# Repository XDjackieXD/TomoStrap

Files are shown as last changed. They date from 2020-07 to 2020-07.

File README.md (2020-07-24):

 # TomoStrap
 
 The code residing in the "microcontroller" and "pebble" directories was written by me, Jakob (Jack/XDjackieXD), as part of the diploma thesis you are required to do for your A Level at a higher technical school in Austria.
 The KiCAD files inside the "hardware" directory, designed by Jakob Z., represent the hardware the aforementioned code runs on.
 
 ## Introduction
 
 The main topic of the diploma thesis was to build a device similar to http://chrisharrison.net/projects/tomo/tomo.pdf while increasing mobility by using a Pebble smartwatch as the base.
 During development I snuck in a MAX30102 pulseoximeter which basically is the main feature as of now.
 
 ## Usage
 
 ### Microcontroller Firmware
 
 To compile the Firmware for the KL03 ARM processor, it'll be the easiest route to install the kinetis design studio. The hardware abstraction layer was generated using NXP's MCUXpresso tool.
 Most parts of the code are written in a way that should allow for fairly easy porting to other microcontroller platforms.
 Currently the handlers for data received are inside the library. Changing this to callbacks should be easy though.
 The firmware isn't complete by any means but contineous SpO2 and pulse measurements are working as intended. Things that need to be addressed before "production" use include proper power management and automatic gain control for the MAX30102's LEDs and configurable ADC ranges as those values are currently hard coded which lead to unreliable measurements in many situations.
 
 ### Pebble App
 
 The included pebble app is able to display any SpO2 and pulse data sent by the microcontroller. Impedance data is currently only printed into the debug log of the Pebble app.
 
 ## License
 
 All code written by me and the SpO2 calculation library is licensed under the MIT license (LICENSE-software.txt).
 The dstring library used for SpO2 debugging using FlexiPlot is licensed under the Creative Commons license (LICENSE-dstring.txt).
 All other source code files included in the microcontroller firmware directory (everything not inside of the "source" directory) is licensed under the respective licenses stated in the source file headers.

 The hardware is Licensed under the terms of the Creative Commons Attribution Sharealike 4.0 license (LICENSE-hardware.txt) with the exception of the kicad library by Michael Cousins which is licensed under the terms of the Creative Commons Attribution Sharealike 3.0 Unported license (LICENSE-kicad-libs.txt).

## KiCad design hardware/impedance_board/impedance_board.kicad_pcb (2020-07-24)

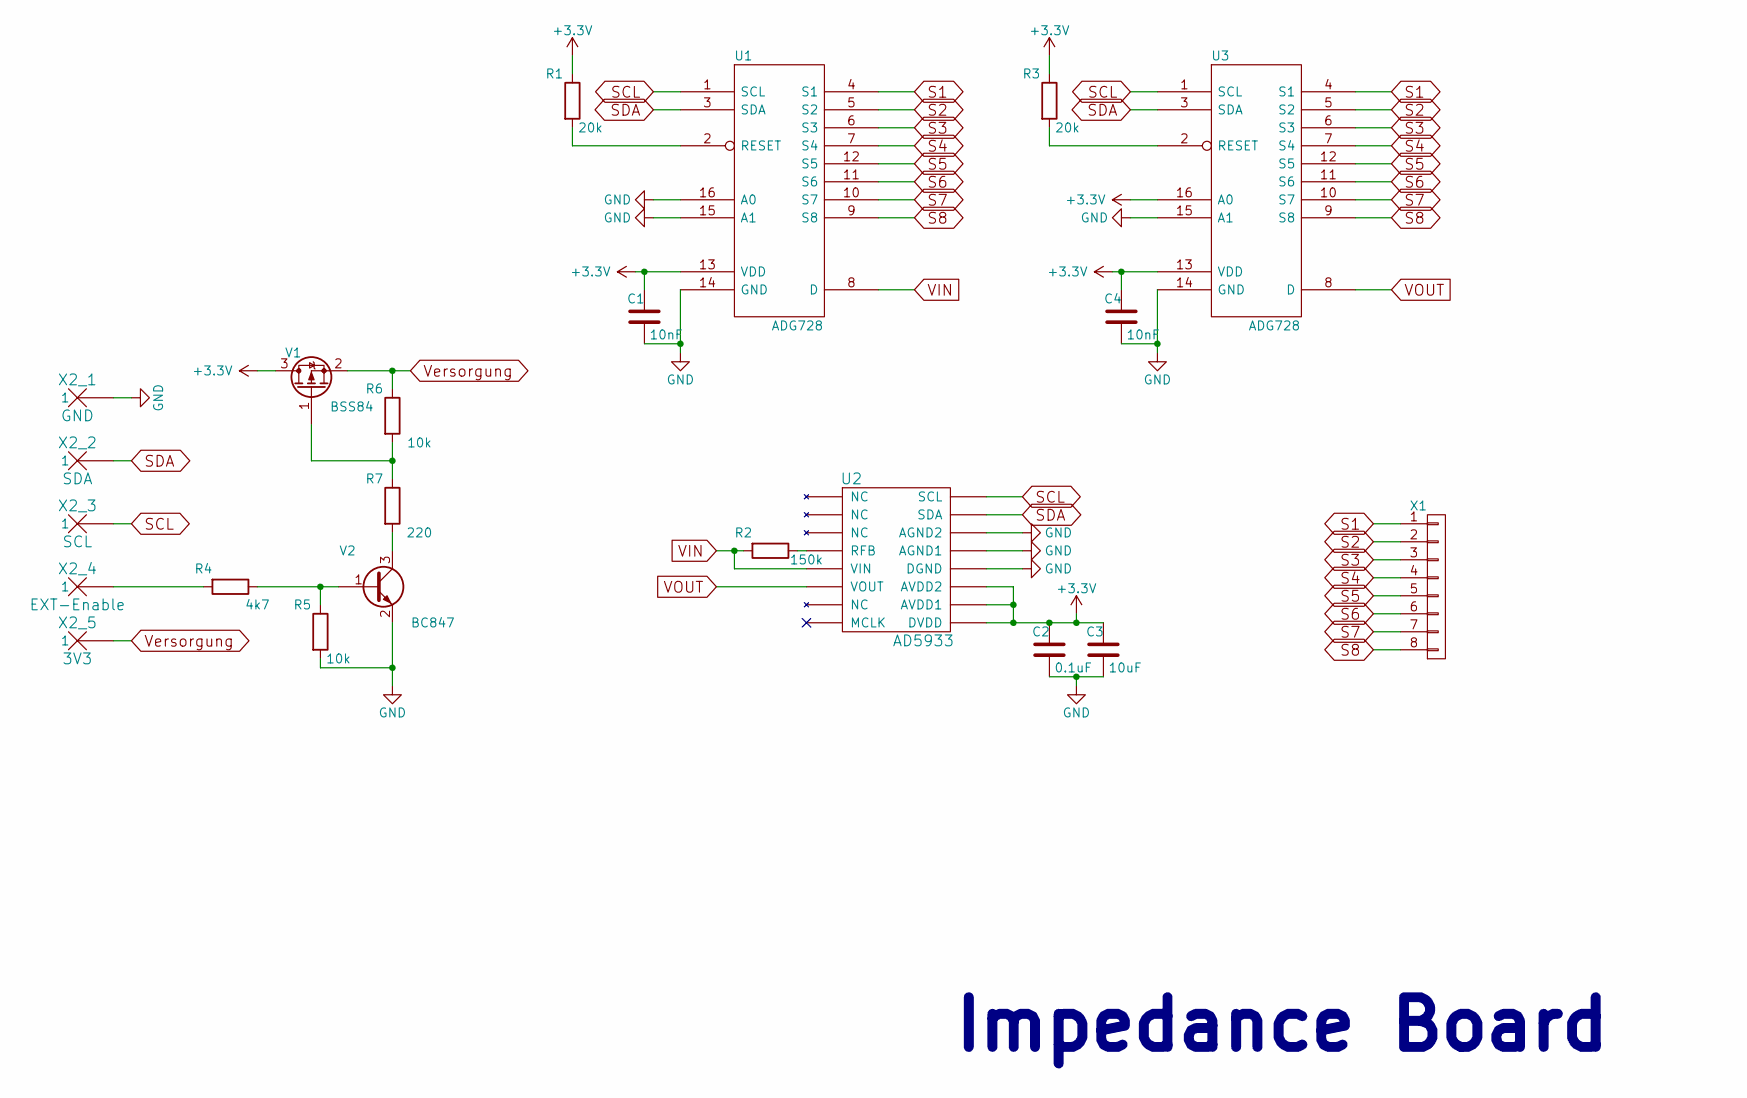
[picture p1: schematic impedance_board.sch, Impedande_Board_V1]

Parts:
C1, C4: 10nF; C_0805_HandSoldering
C2: 0.1uF; C_0805_HandSoldering
C3: 10uF; C_1206_HandSoldering
R1, R3: 20k; R_0805_HandSoldering
R2: 150k; R_0805_HandSoldering
R4: 4k7; R_0805_HandSoldering
R5, R6: 10k; R_0805_HandSoldering
R7: 220; R_0805_HandSoldering
U1, U3: ADG728; TSSOP16
U2: AD5933; SSOP16
V1: BSS84; SOT-23_Handsoldering
V2: BC847; SOT-23_Handsoldering
X1: CONN_01X08; JST_GH_SM08B-GHS-TB_08x1.25mm_Angled
X2_1: GND; 1Pin
X2_2: SDA; 1Pin
X2_3: SCL; 1Pin
X2_4: EXT-Enable; 1Pin
X2_5: 3V3; 1Pin

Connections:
+3V3: C1.1, C2.1, C3.1, C4.1, R1.1, R3.1, U1.13 (VDD), U2.9 (DVDD), U2.10 (AVDD1), U2.11 (AVDD2), U3.13 (VDD), U3.16 (A0), V1.3 (D)
GND: C1.2, C2.2, C3.2, C4.2, R5.2, U1.14 (GND), U1.15 (A1), U1.16 (A0), U2.12 (DGND), U2.13 (AGND1), U2.14 (AGND2), U3.14 (GND), U3.15 (A1), V2.2 (E), X2_1.1
unnamed: R1.2, U1.2 (RESET)
unnamed: R2.1, U2.4 (RFB)
unnamed: R3.2, U3.2 (RESET)
unnamed: R4.1, R5.1, V2.1 (B)
unnamed: R4.2, X2_4.1
unnamed: R6.2, R7.1, V1.1 (G)
unnamed: R7.2, V2.3 (C)
S1: U1.4 (S1), U3.4 (S1), X1.1
S2: U1.5 (S2), U3.5 (S2), X1.2
S3: U1.6 (S3), U3.6 (S3), X1.3
S4: U1.7 (S4), U3.7 (S4), X1.4
S5: U1.12 (S5), U3.12 (S5), X1.5
S6: U1.11 (S6), U3.11 (S6), X1.6
S7: U1.10 (S7), U3.10 (S7), X1.7
S8: U1.9 (S8), U3.9 (S8), X1.8
SCL: U1.1 (SCL), U2.16 (SCL), U3.1 (SCL), X2_3.1
SDA: U1.3 (SDA), U2.15 (SDA), U3.3 (SDA), X2_2.1
VIN: R2.2, U1.8 (D), U2.5 (VIN)
VOUT: U2.6 (VOUT), U3.8 (D)
Versorgung: R6.1, V1.2 (S), X2_5.1

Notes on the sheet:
Impedance Board

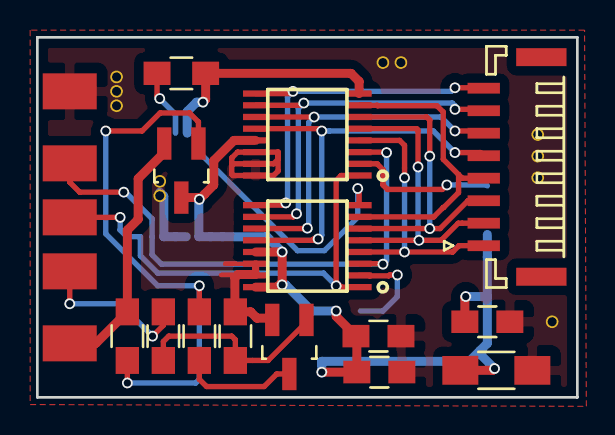
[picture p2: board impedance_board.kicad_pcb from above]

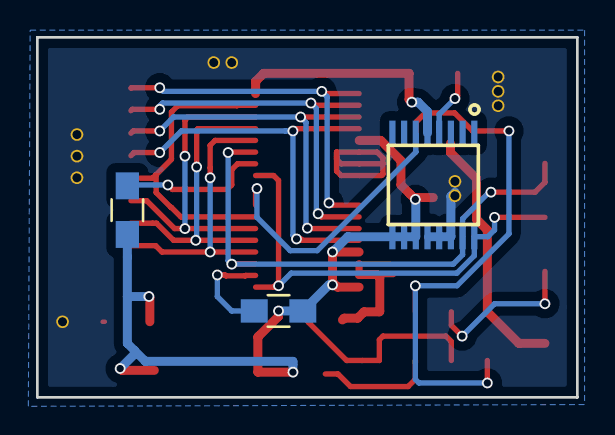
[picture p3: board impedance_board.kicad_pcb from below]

Board: 2 copper layers, 30.0 x 20.0 mm, 22 parts (3 on the bottom side), 22 nets.

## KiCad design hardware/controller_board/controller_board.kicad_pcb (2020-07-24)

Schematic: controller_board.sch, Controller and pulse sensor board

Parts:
C1: 10µ; A_3216-18R; mouser 77-VJ1206V106ZXQTBC
C2: 4.7µ; A_3216-18R; mouser 77-VJ1206V475MXJTBC
C3: 10n; C0805; mouser 710-885012207066
C4: 1µ; A_3216-18R; mouser 77-VJ1206Y105MXJTBC
C5: 100n; C0805; mouser 710-885012207072
EXT-ENABLE12: SMD1_27-2_54
EXT-GND12: SMD1_27-2_54
EXT-SCL12: SMD1_27-2_54
EXT-SDA12: SMD1_27-2_54
EXT-VCC12: SMD1_27-2_54
IC1: LP2985; TI-LP2985; mouser 595-LP2985-33DBVR
IC2: 74LVC1G07DBV; SOT23-5; mouser 595-SN74LVC1G07DBVR
IC3: MAX30102EFD+; MAXIM-MAX30100; mouser 700-MAX30102EFD+
PEBBLE-DATA12: SMD1_27-2_54
PEBBLE-GND1, PEBBLE-GND2: SMD1_27-2_54
PEBBLE-VCC12: SMD1_27-2_54
R1, R2, R3, R4: 4k7; M0805; mouser 667-ERJ-6GEYJ472V
R5: 10k; M0805; mouser 667-ERJ-6ENF1003V
SWD-CLK12: TPB1,27; B1_27
SWD-DIO12: TPB1,27; B1_27
SWD-GND12: TPB1,27; B1_27
SWD-RESET12: TPB1,27; B1_27
U1: MKL03Z32VFG4; 98ASA00525D; mouser 841-MKL03Z32VFG4
V1, V2: ESDA6V1L; SOT-23; mouser 511-ESDA6V1L
VP_0, VP_1, VP_2, VP_3, VP_4, VP_5, VP_6, VP_7, VP_8, VP_9, VP_10, VP_11: VPDEV0; VPAC0

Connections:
3V3: C1.+, C4.+, C5.1, EXT-VCC12.1, IC1.1 (VIN), IC2.5 (VCC), IC3.9 (R_LED+), IC3.10 (IR_LED+), PEBBLE-VCC12.1, R1.2, R2.2, R3.2, R4.2, R5.2, U1.1 (VDD), V1.2; also elsewhere on the board
/1.8ON: IC1.3 (ON/OFF), R4.1, U1.9 (PTB1/IRQ_6)
/EXT-ENABLE: EXT-ENABLE12.1, U1.13 (PTB5/IRQ_12)
/INT: IC3.13 (INT), R3.1, U1.10 (PTB2/IRQ_7)
/N$1: C3.1, IC1.4 (BYPASS)
/N$3: C2.+, IC1.5 (VOUT), IC3.11 (VDD)
/RESET: SWD-RESET12.TP, U1.15 (PTA1/IRQ_1/LPTMR0_ALT1)
/RX: IC2.4 (O), PEBBLE-DATA12.1, R5.1, U1.4 (PTA4), V1.1; also elsewhere on the board
/SCL: EXT-SCL12.1, IC3.2 (SCL), R2.1, U1.11 (PTB3/IRQ_10), V2.1; also elsewhere on the board
/SDA: EXT-SDA12.1, IC3.3 (SDA), R1.1, U1.12 (PTB4/IRQ_11), V2.2; also elsewhere on the board
/SWD-CLK: SWD-CLK12.TP, U1.14 (PTA0/IRQ_0/LLWU_P7)
/SWD-DIO: SWD-DIO12.TP, U1.16 (PTA2)
/TX: IC2.2 (I), U1.3 (PTA3)
GND: C1.-, C2.-, C3.2, C4.-, C5.2, EXT-GND12.1, IC1.2 (GND), IC2.3 (GND), IC3.4 (PGND), IC3.12 (GND), PEBBLE-GND1.1, PEBBLE-GND2.1, SWD-GND12.TP, U1.2 (VSS), U1.17 (EPAD), V1.3, V2.3, VP_0.VP, VP_1.VP, VP_2.VP, VP_3.VP, VP_4.VP, VP_5.VP, VP_6.VP, VP_7.VP, VP_8.VP, VP_9.VP, VP_10.VP, VP_11.VP; also elsewhere on the board

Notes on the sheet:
IC3
MAX30102
Controller Board

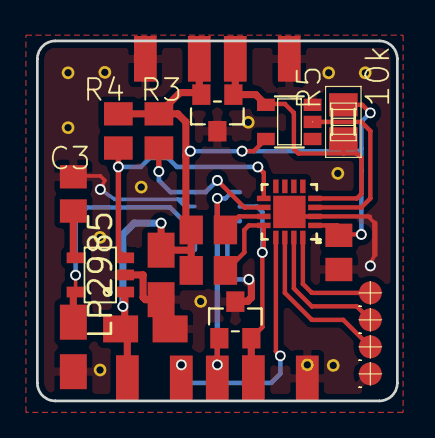
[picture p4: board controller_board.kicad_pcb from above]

Board: 2 copper layers, 20.0 x 20.0 mm, 42 parts (0 on the bottom side), 14 nets.

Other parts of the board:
D1, D2: ESDA6V1L; SOT-23
VP_10#2: VPDEV0; VPAC0

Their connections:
3V3: D1.2; also elsewhere on the board
/RX: D1.1; also elsewhere on the board
/SCL: D2.1; also elsewhere on the board
/SDA: D2.2; also elsewhere on the board
GND: D1.3, D2.3, VP_10#2.VP; also elsewhere on the board

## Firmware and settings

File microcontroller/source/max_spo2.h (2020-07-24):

/*
 * max_spo2.h
 *
 * modified version of
 * https://github.com/xcoder123/MAX30100/
 * to work with the max30102
 */

#ifndef SOURCE_MAX_SPO2_H_
#define SOURCE_MAX_SPO2_H_

#include "fsl_common.h"
#include "max30102.h"
#include <math.h>

/*----------------------------------------------*/
/* Config defines, you can tailor to your needs */
/*----------------------------------------------*/

/* MAX30100 parameters */
#define DEFAULT_OPERATING_MODE            MAX30100_MODE_SPO2_HR
/*!!!IMPORTANT
 * You can't just throw these two values at random. Check Check table 8 in datasheet on page 19.
 * 100hz + 1600us is max for that resolution
 */
#define DEFAULT_SAMPLING_RATE             MAX30100_SAMPLING_RATE_100HZ
#define DEFAULT_LED_PULSE_WIDTH           MAX30100_PULSE_WIDTH_1600US_ADC_16

#define DEFAULT_IR_LED_CURRENT            0x66
#define STARTING_RED_LED_CURRENT          0x66


/* Adjust RED LED current balancing*/
#define MAGIC_ACCEPTABLE_INTENSITY_DIFF         65000
#define RED_LED_CURRENT_ADJUSTMENT_MS           500

/* SaO2 parameters */
#define RESET_SPO2_EVERY_N_PULSES     4

/* Filter parameters */
#define ALPHA 0.95  //dc filter alpha value
#define MEAN_FILTER_SIZE        15

/* Pulse detection parameters */
#define PULSE_MIN_THRESHOLD         100 //300 is good for finger, but for wrist you need like 20, and there is shitloads of noise
#define PULSE_MAX_THRESHOLD         2000
#define PULSE_GO_DOWN_THRESHOLD     1

#define PULSE_BPM_SAMPLE_SIZE       20 //Moving average size





/* Enums, data structures and typdefs. DO NOT EDIT */
typedef struct{
  bool pulseDetected;
  float heartBPM;

  float irCardiogram;

  float irDcValue;
  float redDcValue;

  float SaO2;

  uint32_t lastBeatThreshold;

  float dcFilteredIR;
  float dcFilteredRed;

  uint32_t rawIr;
  uint32_t rawRed;
} pulseoxymeter_t;

typedef enum PulseStateMachine {
    PULSE_IDLE,
    PULSE_TRACE_UP,
    PULSE_TRACE_DOWN
} PulseStateMachine;

typedef struct {
  uint32_t rawIR;
  uint32_t rawRed;
} fifo_t;

typedef struct {
  float w;
  float result;
} dcFilter_t;

typedef struct {
  float v[2];
  float result;
} butterworthFilter_t;

typedef struct {
  float values[MEAN_FILTER_SIZE];
  uint8_t index;
  float sum;
  uint8_t count;
} meanDiffFilter_t;

/* MAX30100 register and bit defines, DO NOT EDIT */
#define MAX30100_DEVICE                   0x57

//Part ID Registers
#define MAX30100_REV_ID                   0xFE
#define MAX30100_PART_ID                  0xFF

//status registers
#define MAX30100_INT_STATUS               0x00
#define MAX30100_INT_ENABLE               0x01

//Fifo registers
#define MAX30100_FIFO_WRITE               0x02
#define MAX30100_FIFO_OVERFLOW_COUNTER    0x03
#define MAX30100_FIFO_READ                0x04
#define MAX30100_FIFO_DATA                0x05

//Config registers
#define MAX30100_MODE_CONF                0x06
#define MAX30100_SPO2_CONF                0x07
#define MAX30100_LED_CONF                 0x09

//Temperature registers
#define MAX30100_TEMP_INT                 0x16
#define MAX30100_TEMP_FRACTION            0x17


//Bit defines MODE Regsiter
#define MAX30100_MODE_SHDN                (1<<7)
#define MAX30100_MODE_RESET               (1<<6)
#define MAX30100_MODE_TEMP_EN             (1<<3)

//Bit defines SpO2 register
#define MAX30100_SPO2_HI_RES_EN           (1 << 6)

typedef enum LEDCurrent {
    MAX30100_LED_CURRENT_0MA              = 0x00,
    MAX30100_LED_CURRENT_4_4MA            = 0x01,
    MAX30100_LED_CURRENT_7_6MA            = 0x02,
    MAX30100_LED_CURRENT_11MA             = 0x03,
    MAX30100_LED_CURRENT_14_2MA           = 0x04,
    MAX30100_LED_CURRENT_17_4MA           = 0x05,
    MAX30100_LED_CURRENT_20_8MA           = 0x06,
    MAX30100_LED_CURRENT_24MA             = 0x07,
    MAX30100_LED_CURRENT_27_1MA           = 0x08,
    MAX30100_LED_CURRENT_30_6MA           = 0x09,
    MAX30100_LED_CURRENT_33_8MA           = 0x0A,
    MAX30100_LED_CURRENT_37MA             = 0x0B,
    MAX30100_LED_CURRENT_40_2MA           = 0x0C,
    MAX30100_LED_CURRENT_43_6MA           = 0x0D,
    MAX30100_LED_CURRENT_46_8MA           = 0x0E,
    MAX30100_LED_CURRENT_50MA             = 0x0F
} LEDCurrent;

    void spo2( ledMode mode,
    		sampleRate samplingRate,
    		pulseWidth pulseWidth,
            LEDCurrent irCurrent);

    pulseoxymeter_t spo2_update(uint32_t samples, uint16_t samples_per_second);

    void spo2_setLEDCurrents( uint8_t redLedCurrent, uint8_t IRLedCurrent );
    fifo_t spo2_readFIFO();

    dcFilter_t spo2_dcRemoval(float x, float prev_w, float alpha);
    void spo2_lowPassButterworthFilter( float x, butterworthFilter_t * filterResult );
    float spo2_meanDiff(float M, meanDiffFilter_t* filterValues);

    bool spo2_detectPulse(float sensor_value);
    void spo2_balanceIntesities( float redLedDC, float IRLedDC );



#endif /* SOURCE_MAX_SPO2_H_ */

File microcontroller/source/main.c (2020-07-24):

#include "board.h"
#include "pin_mux.h"
#include "clock_config.h"
#include "fsl_port.h"
#include "fsl_common.h"
#include "fsl_gpio.h"
#include "pebble_smartstrap.h"
#include "i2c_hal.h"
#include "max30102.h"
#include "max_spo2.h"
#include "adg728.h"
#include "ad5933.h"

#include "dstring.h"
#include "fsl_lpuart.h"

static void delay(volatile uint32_t nof) {
  while(nof!=0) {
    __asm("NOP");
    nof--;
  }
}



//------------------------------ SpO2 & Pulse ------------------------------
#define MAX30102_ENABLE_GPIO	GPIOB
#define MAX30102_ENABLE_PORT	PORTB
#define MAX30102_ENABLE_PIN		1U
#define MAX30102_IRQ_GPIO		GPIOB
#define MAX30102_IRQ_PORT		PORTB
#define MAX30102_IRQ_PIN		2U
#define MAX30102_IRQ_HANDLER	PORTB_IRQHandler
#define MAX30102_IRQ			PORTB_IRQn


uint32_t samples = 0;
pulseoxymeter_t result;

//char buffer[60];

void max30102_update() {
	if(max30102_getAvailableSamples() > 0) {
		result = spo2_update(samples, 100);
		samples++;


		//FlexiPlot output for fancy plotting. requires dstring lib to be included
		//if(samples % 10 == 0) {
		//dsprintf_P(buffer, "{P0|IR|0,0,255|%d|RED|255,0,0|%d}\r\n", (int)(result.dcFilteredIR), (int)(result.dcFilteredRed));
		//LPUART_WriteBlocking(LPUART0, buffer, strlen(buffer));
		//dsprintf_P(buffer, "{P1|RED|255,0,255|%d|BEAT|0,0,255|%d}\r\n", (int)(result.irCardiogram*10.0), (int)(result.lastBeatThreshold*10.0));
		//LPUART_WriteBlocking(LPUART0, buffer, strlen(buffer));
		//dsprintf_P(buffer, "{P2|BPM|255,40,0|%d|SaO2|0,0,255|%d}\r\n", (int)(result.heartBPM*10.0), (int)(result.SaO2*10.0));
		//LPUART_WriteBlocking(LPUART0, buffer, strlen(buffer));
		//}

		if(samples % 100 == 0 /*&& pebble_status == PEBBLE_STATUS_CONNECTED*/) {
			set_spo2_send_data((int)(result.heartBPM * 10.0), (int)(result.SaO2 * 10.0), result.pulseDetected);

			pebble_frame_t frame;

			frame.version = 1;
			frame.flags = 4;
			frame.profile = PEBBLE_PROFILE_RAW;
			frame.payload_length = 0;
			pebble_send_frame(frame);
		}
	}
}

// For whatever reason the MAX30102 did not send an interrupt (probably not configured correctly) so polling it is...
/*void MAX30102_IRQ_HANDLER(void) {
	if(GPIO_GetPinsInterruptFlags(MAX30102_IRQ_GPIO) & (1<<MAX30102_IRQ_PIN)){
		GPIO_ClearPinsInterruptFlags(MAX30102_IRQ_GPIO, 1U << MAX30102_IRQ_PIN);

		uint8_t flags = max30102_getInterruptFlags();
		if(flags & (1<<1)) {
			//die temp ready
		}
		if(flags & (1<<7)) {
			uint8_t av_samples = max30102_getAvailableSamples();

			if(pebble_status == PEBBLE_STATUS_CONNECTED) {

			}
		}
	}
}
void max30102_init_irq(void) {
    gpio_pin_config_t max_config = {
        kGPIO_DigitalInput, 0,
    };
    PORT_SetPinInterruptConfig(MAX30102_IRQ_PORT, MAX30102_ENABLE_PIN, kPORT_InterruptFallingEdge);
    EnableIRQ(MAX30102_IRQ);
    GPIO_PinInit(MAX30102_IRQ_GPIO, MAX30102_IRQ_PIN, &max_config);
}*/

//power max30102 1.8V supply on or off
void max30102_power(bool state) {
	if(state){
		GPIO_SetPinsOutput(MAX30102_ENABLE_GPIO, 1<<MAX30102_ENABLE_PIN); /* PTB1 on */
	}else{
		GPIO_ClearPinsOutput(MAX30102_ENABLE_GPIO, 1<<MAX30102_ENABLE_PIN); /* PTB1 off */
	}
}


//------------------------------ Impedance ------------------------------

#define IMPEDANCE_FREQUENCY 1280093 //40kHz
#define IMPEDANCE_SETTING_TIME 128

#define IMPEDANCE_STATE_STANDBY 0x00
#define IMPEDANCE_STATE_STARTED 0x01
#define IMPEDANCE_STATE_AWAITING_COMPLETION 0x02

uint8_t impedance_state = IMPEDANCE_STATE_STANDBY;
uint8_t ele1 = 0;
uint8_t ele2 = 0;
bool impedance_should_measure = false;

void impedance_start_measure() {
	ad5933_reset();
	ad5933_set_op_mode(standby_mode);
	ad5933_set_op_mode(init_start_freq);
	ad5933_set_op_mode(start_sweep);
	impedance_state = IMPEDANCE_STATE_STARTED;
}

void impedance_start_sweep(uint8_t electrode1, uint8_t electrode2) {
	adg728_set(adg728_00, electrode1);
	adg728_set(adg728_01, electrode2);
	delay(100);
	ad5933_set_op_mode(repeat_freq);
	impedance_state = IMPEDANCE_STATE_AWAITING_COMPLETION;
}

void impedance_stop_measure() {
	ad5933_reset();
	ad5933_set_op_mode(standby_mode);
	impedance_state = IMPEDANCE_STATE_STANDBY;
}

bool impedance_get_data() {
	uint8_t tmp = ad5933_get_status();

	if (sent_impedance_data()&& ((tmp & valid_impedance_data) != 0)) {
		impedance_data_t impedance = ad5933_get_impedance();

		set_impedance_send_data(impedance.real, impedance.imaginary, ele1, ele2);

		pebble_frame_t frame;

		frame.version = 1;
		frame.flags = 4;
		frame.profile = PEBBLE_PROFILE_RAW;
		frame.payload_length = 0;
		pebble_send_frame(frame);

		impedance_state = IMPEDANCE_STATE_STARTED;
		return true;
	} else {
		return false;
	}
}

void impedance_loop_handler() {
	/*if(get_impedance_measure()){
		set_impedance_send_data(0, 1, 0, 1);

		pebble_frame_t frame;

		frame.version = 1;
		frame.flags = 4;
		frame.profile = PEBBLE_PROFILE_RAW;
		frame.payload_length = 0;
		pebble_send_frame(frame);
	}*/
	if(impedance_should_measure == false && get_impedance_measure())
		impedance_should_measure = true;

	if (impedance_should_measure == true && impedance_state == IMPEDANCE_STATE_STANDBY) {
		impedance_should_measure = false;
		impedance_start_measure();
	} else if (impedance_state == IMPEDANCE_STATE_STARTED) {
		ele1++;
		if (ele1 >= 8) {
			ele2++;
			ele1 = ele2 + 1;
		}
		impedance_start_sweep(1 << ele1, 1 << ele2);
	} else if (impedance_state == IMPEDANCE_STATE_AWAITING_COMPLETION) {
		if (impedance_get_data()) {
			if (ele2 >= 6) {
				ele1 = 0;
				ele2 = 0;
				impedance_stop_measure();
			}
		}
	}
}




/*!
 * @brief Application entry point.
 */
int main(void) {
  /* Init board hardware. */
  BOARD_InitPins();
  BOARD_BootClockRUN();
  BOARD_InitDebugConsole();
  smartstrap_init();
  i2c_init();

  // In case of "fancy printing" using flexiplot, manually init the serial connectionand DON'T init the smartstrap connection
  /*lpuart_config_t config;
  LPUART_GetDefaultConfig(&config);
  config.baudRate_Bps = 115200;
  config.parityMode = kLPUART_ParityDisabled;
  config.stopBitCount = kLPUART_OneStopBit;
  config.enableTx = true;
  config.enableRx = false;
  LPUART_Init(LPUART0, &config, CLOCK_GetFreq(SYS_CLK));*/

  delay(100);

  
  //init network analyzer for impedance measurement
  ad5933_init(standby_mode, Vpp_2V, gain_x5, clock_internal, IMPEDANCE_FREQUENCY, 1, 1, IMPEDANCE_SETTING_TIME);

  //init max30102 for continous pulse & SpO2 measurement
  max30102_power(true);
  delay(50);
  spo2(modeSpO2, sr200, pw411, 0x66);

  //poll everything because interrupts of the max30102 aren't working corrently :(
  for(;;) {
    delay(120);
    //smartstrap_loop_handler(1);
    impedance_loop_handler();
    max30102_update();
  }

  for(;;) { /* Infinite loop to avoid leaving the main function */
    __asm("NOP"); /* something to use as a breakpoint stop while looping */
  }
}

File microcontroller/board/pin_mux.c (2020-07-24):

/*
 * Copyright (c) 2013 - 2016, Freescale Semiconductor, Inc.
 * All rights reserved.
 *
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
 * o Neither the name of Freescale Semiconductor, Inc. nor the names of its
 *   contributors may be used to endorse or promote products derived from this
 *   software without specific prior written permission.
 *
 * THIS SOFTWARE IS PROVIDED BY THE COPYRIGHT HOLDERS AND CONTRIBUTORS "AS IS" AND
 * ANY EXPRESS OR IMPLIED WARRANTIES, INCLUDING, BUT NOT LIMITED TO, THE IMPLIED
 * WARRANTIES OF MERCHANTABILITY AND FITNESS FOR A PARTICULAR PURPOSE ARE
 * DISCLAIMED. IN NO EVENT SHALL THE COPYRIGHT HOLDER OR CONTRIBUTORS BE LIABLE FOR
 * ANY DIRECT, INDIRECT, INCIDENTAL, SPECIAL, EXEMPLARY, OR CONSEQUENTIAL DAMAGES
 * (INCLUDING, BUT NOT LIMITED TO, PROCUREMENT OF SUBSTITUTE GOODS OR SERVICES;
 * LOSS OF USE, DATA, OR PROFITS; OR BUSINESS INTERRUPTION) HOWEVER CAUSED AND ON
 * ANY THEORY OF LIABILITY, WHETHER IN CONTRACT, STRICT LIABILITY, OR TORT
 * (INCLUDING NEGLIGENCE OR OTHERWISE) ARISING IN ANY WAY OUT OF THE USE OF THIS
 * SOFTWARE, EVEN IF ADVISED OF THE POSSIBILITY OF SUCH DAMAGE.
 */

/* This is a template file for pins configuration created by New Kinetis SDK 2.x Project Wizard. Enjoy! */

#include "fsl_device_registers.h"
#include "fsl_common.h"
#include "fsl_port.h"
#include "pin_mux.h"

#define PIN0_IDX                         0u   /*!< Pin number for pin 0 in a port */
#define PIN1_IDX                         1u   /*!< Pin number for pin 1 in a port */
#define PIN2_IDX                         2u   /*!< Pin number for pin 2 in a port */
#define PIN3_IDX                         3u   /*!< Pin number for pin 3 in a port */
#define PIN4_IDX                         4u   /*!< Pin number for pin 4 in a port */
#define PIN5_IDX                         5u   /*!< Pin number for pin 5 in a port */
#define PIN6_IDX                         6u   /*!< Pin number for pin 6 in a port */
#define PIN7_IDX                         7u   /*!< Pin number for pin 7 in a port */
#define SOPT5_LPUART0RXSRC_LPUART_RX  0x00u   /*!< LPUART0 Receive Data Source Select: LPUART_RX pin */

/*******************************************************************************
 * Code
 ******************************************************************************/
/*!
 * @brief Initialize all pins used in this example
 */
void BOARD_InitPins(void)
{
	  CLOCK_EnableClock(kCLOCK_PortA);                           /* Port A Clock Gate Control: Clock enabled */
	  CLOCK_EnableClock(kCLOCK_PortB);                           /* Port B Clock Gate Control: Clock enabled */

	  PORT_SetPinMux(PORTA, PIN0_IDX, kPORT_MuxAlt3);            /* PORTA0 (pin 14) is configured as SWD_CLK */
	  PORT_SetPinMux(PORTA, PIN1_IDX, kPORT_MuxAlt3);            /* PORTA1 (pin 15) is configured as RESET_b */
	  PORT_SetPinMux(PORTA, PIN2_IDX, kPORT_MuxAlt3);            /* PORTA2 (pin 16) is configured as SWD_DIO */
	  PORT_SetPinMux(PORTA, PIN3_IDX, kPORT_MuxAlt4);            /* PORTA3 (pin 3) is configured as LPUART0_TX */
	  PORT_SetPinMux(PORTA, PIN4_IDX, kPORT_MuxAlt4);            /* PORTA4 (pin 4) is configured as LPUART0_RX */
	  PORT_SetPinMux(PORTA, PIN5_IDX, kPORT_PinDisabledOrAnalog); /* PORTA5 (pin 5) is disabled */
	  PORT_SetPinMux(PORTA, PIN6_IDX, kPORT_PinDisabledOrAnalog); /* PORTA6 (pin 6) is disabled */
	  PORT_SetPinMux(PORTA, PIN7_IDX, kPORT_PinDisabledOrAnalog); /* PORTA7 (pin 7) is disabled */
	  PORT_SetPinMux(PORTB, PIN0_IDX, kPORT_MuxAsGpio);          /* PORTB0 (pin 8) is configured as PTB0 */
	  PORT_SetPinMux(PORTB, PIN1_IDX, kPORT_MuxAsGpio);          /* PORTB1 (pin 9) is configured as PTB1 */
	  PORT_SetPinMux(PORTB, PIN2_IDX, kPORT_MuxAsGpio);          /* PORTB2 (pin 10) is configured as PTB2 */
	  PORT_SetPinMux(PORTB, PIN3_IDX, kPORT_MuxAlt2);            /* PORTB3 (pin 11) is configured as I2C0_SCL */
	  PORT_SetPinMux(PORTB, PIN4_IDX, kPORT_MuxAlt2);            /* PORTB4 (pin 12) is configured as I2C0_SDA */
	  PORT_SetPinMux(PORTB, PIN5_IDX, kPORT_MuxAsGpio);          /* PORTB5 (pin 13) is configured as PTB5 */
	  SIM->SOPT5 = ((SIM->SOPT5 &
	    (~(SIM_SOPT5_LPUART0RXSRC_MASK)))                        /* Mask bits to zero which are setting */
	      | SIM_SOPT5_LPUART0RXSRC(SOPT5_LPUART0RXSRC_LPUART_RX) /* LPUART0 Receive Data Source Select: LPUART_RX pin */
	    );

	  GPIO_PinInit(GPIOB, 5u, &EXT_ENABLE_configOutput); /* mux PTB5 as output */
	  GPIO_PinInit(GPIOB, 1u, &EXT_ENABLE_configOutput); /* mux PTB1 as output */
}

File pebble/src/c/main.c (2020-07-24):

#include <pebble.h>
#include "common.h"
#include "main_window.h"

static const SmartstrapServiceId s_service_id = SMARTSTRAP_RAW_DATA_SERVICE_ID;
static const SmartstrapAttributeId s_attribute_id = SMARTSTRAP_RAW_DATA_ATTRIBUTE_ID;
static SmartstrapAttribute *s_attribute;
static bool s_service_available = false;

int32_t pulse = -1;
int32_t oxygen = -1;

#define KEY_OXYGEN 0x00
#define KEY_IMPEDANCE 'i'

// ----- Smartstrap -----

static void strap_availability_handler(SmartstrapServiceId service_id, bool is_available) {
  // A service's availability has changed
  APP_LOG(APP_LOG_LEVEL_INFO, "Service %d is %s available", (int)service_id, is_available ? "now" : "NOT");

  // Remember if the raw service is available
  s_service_available = (is_available && service_id == s_service_id);
  
  if(!s_service_available){
    pulse = -1;
    oxygen = -1;
    main_window_update();
  }
}

static void strap_notify_handler(SmartstrapAttribute *attribute) {
  // Received data message from smartstrap
  APP_LOG(APP_LOG_LEVEL_INFO, "Got notification from smartstrap");
  
  //read data
  smartstrap_attribute_read(attribute);
}

static void strap_read_handler(SmartstrapAttribute *attribute, SmartstrapResult result, const uint8_t *data, size_t length) {
  if(result == SmartstrapResultOk) {
    // Data has been read into the data buffer provided
    //APP_LOG(APP_LOG_LEVEL_INFO, "Smartstrap sent: %x", data[0]);
    
    if(data[0] == KEY_OXYGEN && length == 10) {
      //APP_LOG(APP_LOG_LEVEL_INFO, "Got SpO2 data \\o/");
      
      pulse = (data[2] << 24) | (data[3] << 16) | (data[4] << 8) | data[5];
      oxygen = (data[6] << 24) | (data[7] << 16) | (data[8] << 8) | data[9];
      
      if(pulse >= 2000 || pulse <= 100)
        pulse = -1;
      if(oxygen >= 1000 || oxygen <= 500)
        oxygen = -1;
      
      main_window_update();
      
      //APP_LOG(APP_LOG_LEVEL_INFO, "Data: %x %x%x%x%x %x%x%x%x", data[1], data[2], data[3], data[4], data[5], data[6], data[7], data[8], data[9]);
      APP_LOG(APP_LOG_LEVEL_INFO, "Pulse: %d, Oxygen: %d", pulse, oxygen);
    } else if(data[0] == KEY_IMPEDANCE && length == 7) {
      int16_t real = (data[1] << 8) | data[2];
      int16_t imaginary = (data[3] << 8) | data[4];
      uint8_t electrode1 = data[5];
      uint8_t electrode2 = data[6];
      
      APP_LOG(APP_LOG_LEVEL_INFO, "Real: %d, Imaginary: %d, Electrodes: %d, %d", real, imaginary, electrode1, electrode2);
    }
  } else {
    // Some error has occured
    APP_LOG(APP_LOG_LEVEL_ERROR, "Error in read handler: %d", (int)result);
  }
}

static void strap_init() {
  s_attribute = smartstrap_attribute_create(s_service_id, s_attribute_id, 64);

  // Subscribe to smartstrap events
  smartstrap_subscribe((SmartstrapHandlers) {
    .availability_did_change = strap_availability_handler,
    .notified = strap_notify_handler,
    .did_read = strap_read_handler
  });
}

static void select_click_handler(ClickRecognizerRef recognizer, void *context) {
  if(s_service_available) {
    size_t buff_size;
    uint8_t *buffer;
    smartstrap_attribute_begin_write(s_attribute, &buffer, &buff_size);
    snprintf((char*)buffer, buff_size, "i");
    smartstrap_attribute_end_write(s_attribute, buff_size, false);
  }
}

static void click_config_provider(void *context) {
  window_single_click_subscribe(BUTTON_ID_SELECT, select_click_handler);
}


// ----- Init -----

void handle_init(void) {
  strap_init();
  main_window_init(&pulse, &oxygen);
  window_set_click_config_provider(get_main_window(), click_config_provider);
}

void handle_deinit(void) {
  main_window_deinit();
}

int main(void) {
  handle_init();
  app_event_loop();
  handle_deinit();
}
